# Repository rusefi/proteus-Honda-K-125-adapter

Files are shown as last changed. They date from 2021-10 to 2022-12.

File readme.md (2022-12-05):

[Connector Pinout Spreadhseet, with links to wiring drawings](https://docs.google.com/spreadsheets/d/1G6FDarE99hbd0HSs6bh5kEkZy6p-kYTxa0NcJpE1HUc)

Part of https://github.com/rusefi/rusefi/wiki/Proteus#adapters family

https://github.com/rusefi/rusefi/wiki/Proteus-Honda125

https://www.ebay.com/itm/334206656537

First test mule https://rusefi.com/forum/viewtopic.php?f=2&t=1955

https://github.com/rusefi/rusefi/wiki/Vault-Of-Honda-OEM#dbc-k

https://github.com/rusefi/rusefi/wiki/Honda-Element

x

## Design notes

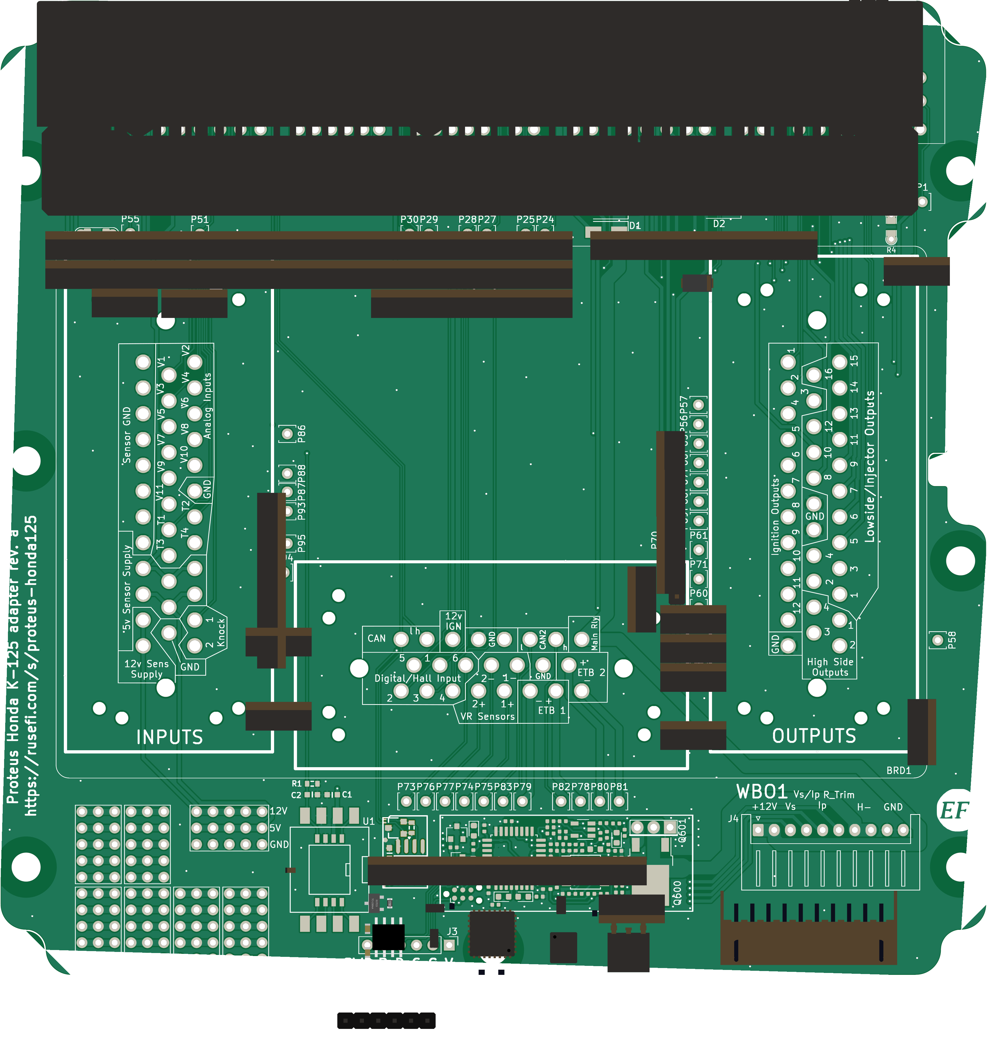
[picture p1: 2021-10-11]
proteus125honda/boards/proteus125honda-a/board/proteus125honda-a.png

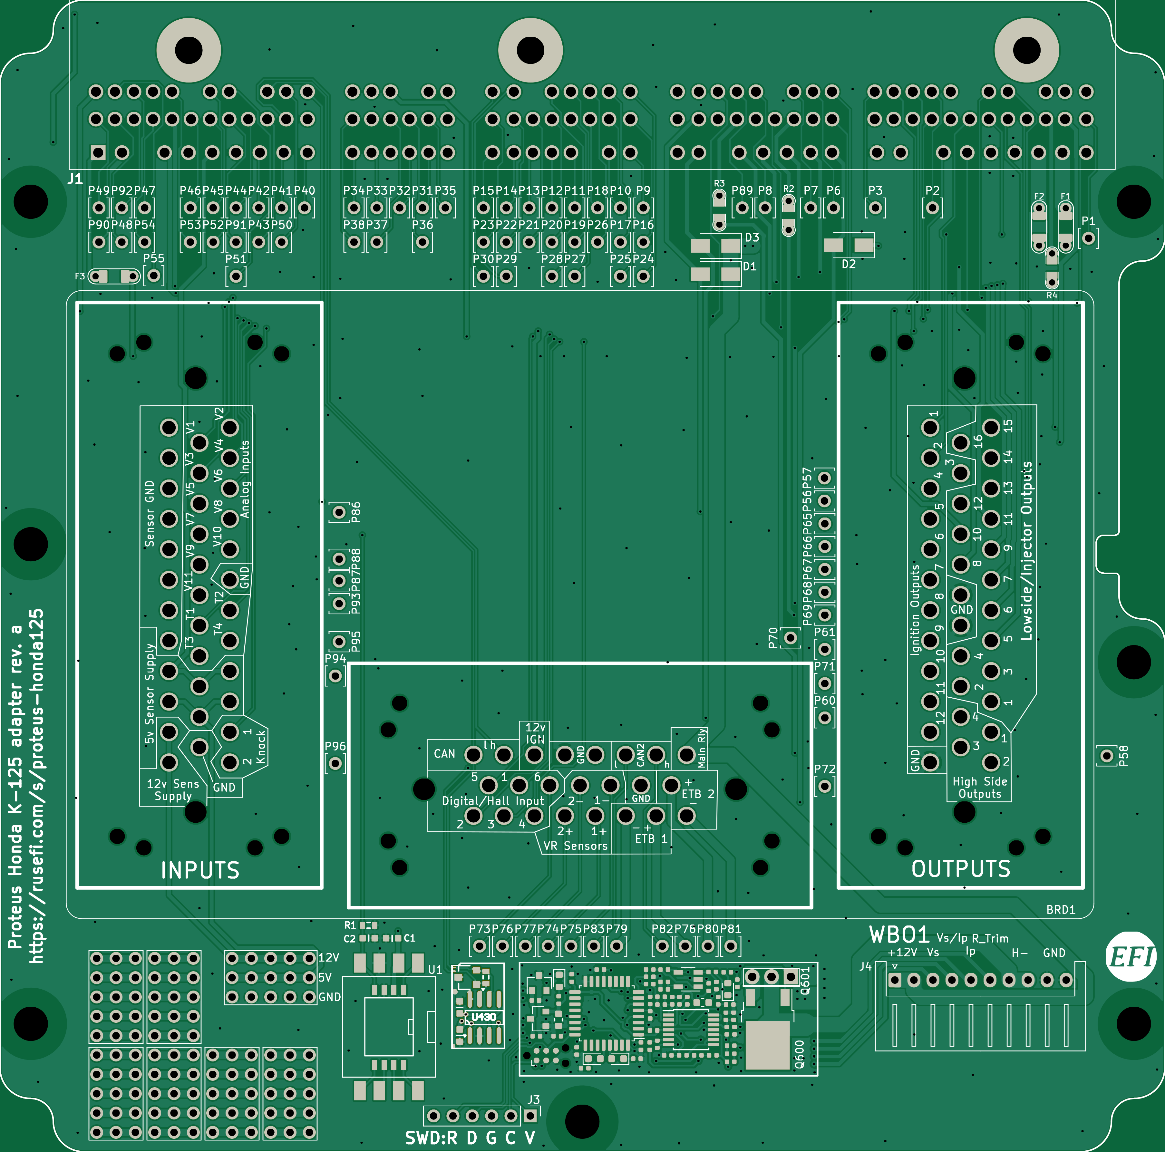
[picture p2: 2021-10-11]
proteus125honda/boards/proteus125honda-a/board/misc/proteus125honda-a-top.png

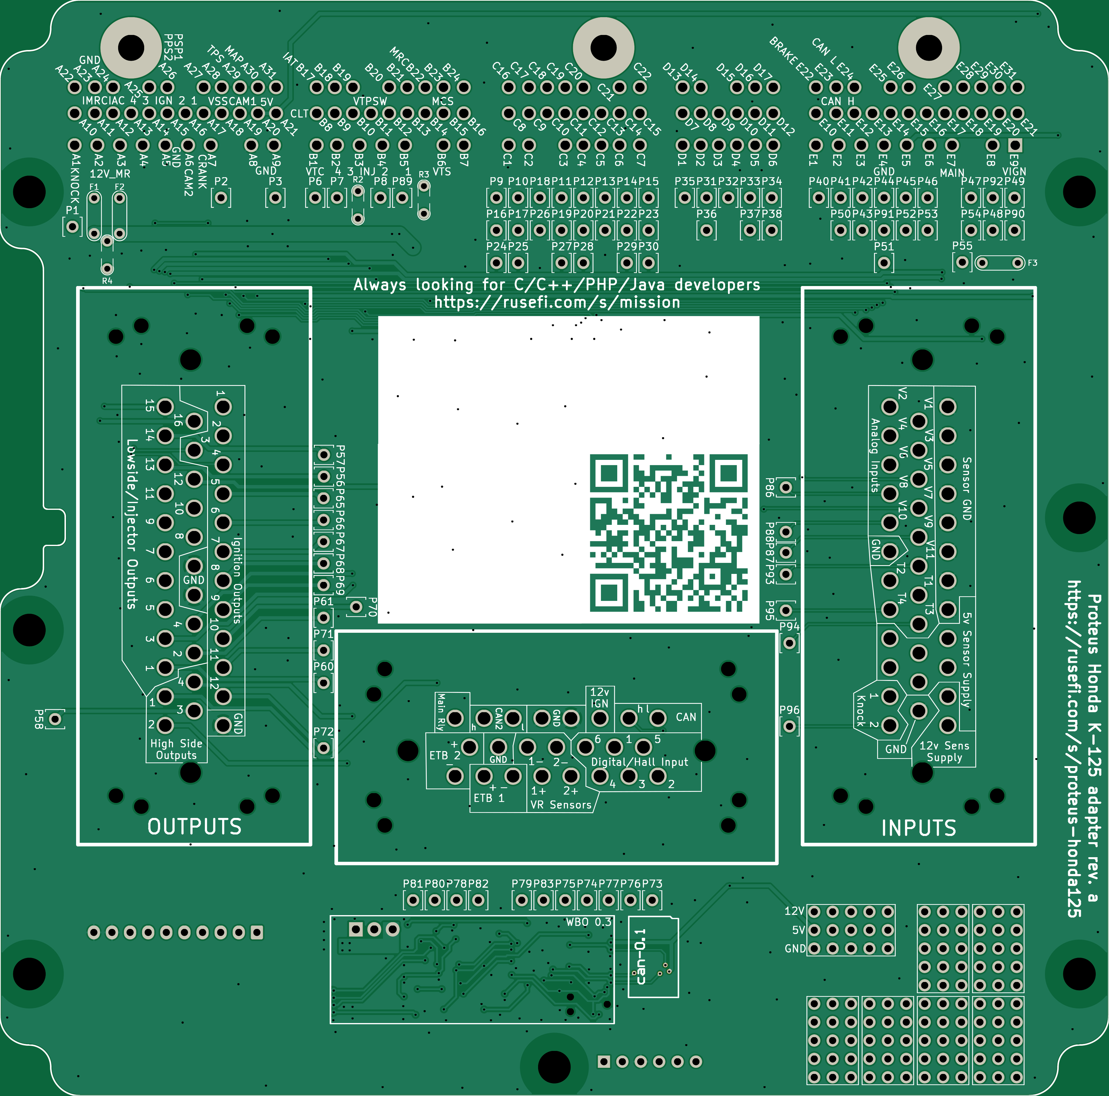
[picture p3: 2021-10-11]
proteus125honda/boards/proteus125honda-a/board/misc/proteus125honda-a-bottom.png

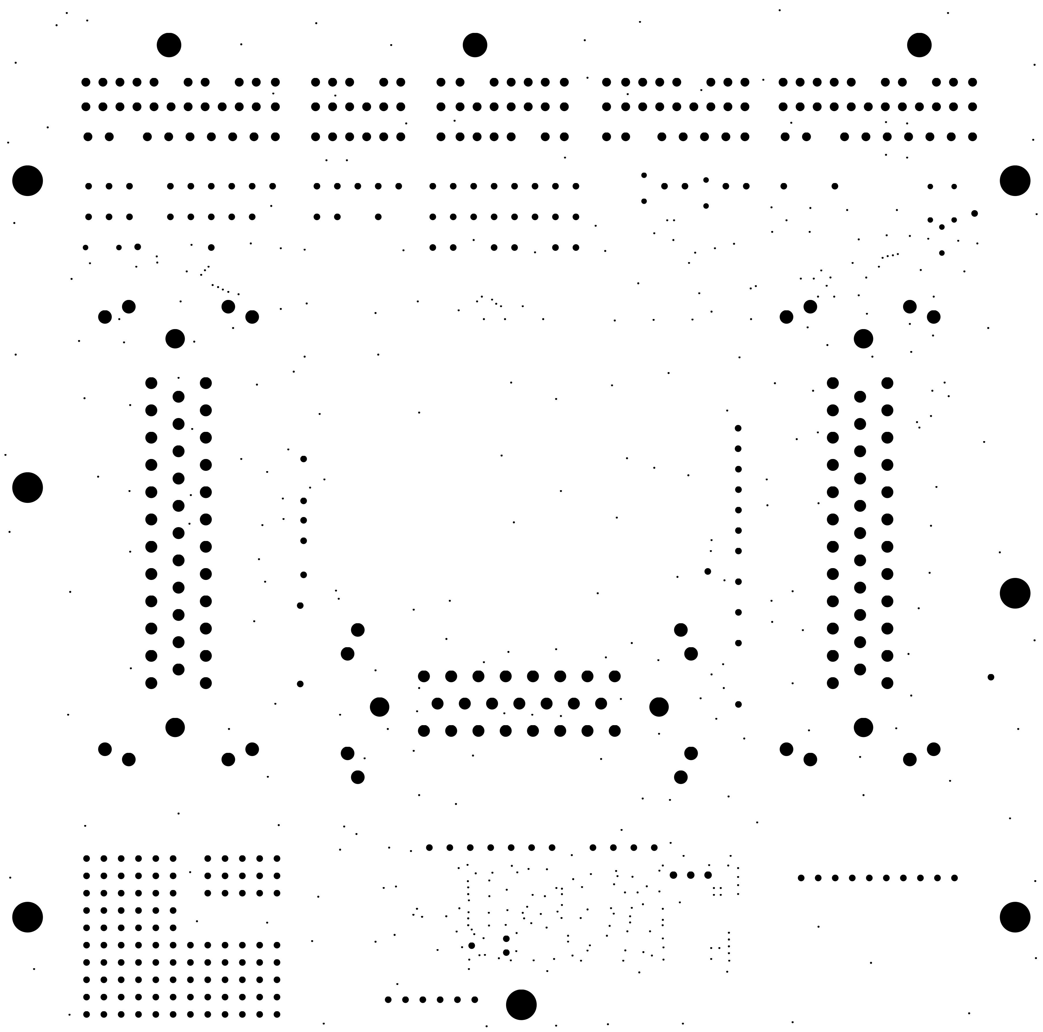
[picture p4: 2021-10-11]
proteus125honda/boards/proteus125honda-a/board/misc/proteus125honda-a-outline.png

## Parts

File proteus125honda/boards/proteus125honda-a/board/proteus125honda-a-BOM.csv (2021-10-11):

Comment | Designator | Footprint | LCSC Part #
proteus | BRD1 | proteus
100n | C1, C430, C431 | C0603 | C14663
47p | C2 | C0603 | C1671
D_Schottky | D1, D2 | D_SMA | C8678
DNP | D3 | D_SMA
Fuse-Pad-Pad | F1, F2, F3 | PAD-1206-PAD | C182446
PROTO_AREA | G1 | PROTO_AREA
PROTO_AREA | G2 | PROTO_AREA
PROTO_AREA | G3 | PROTO_AREA
PROTO_AREA | G4 | PROTO_AREA
PROTO_AREA | G5 | PROTO_AREA
RUSEFI_LOGO | G6 | rusefi_logo
PROTO_AREA | G7 | PROTO_AREA
PROTO_AREA | G8 | PROTO_AREA
1318612-1 | J1 | TE_1318612-1
Conn_01x06 | J3 | PinHeader_1x06_P2.54mm_Vertical
XH-10AW | J4 | JST_XH_S10B-XH-A_1x10_P2.50mm_Horizontal | C14652
Conn_01x01 | J7 | MountingHole_4.5mm
Conn_01x01 | J8 | MountingHole_4.5mm
Conn_01x01 | J9 | MountingHole_4.5mm
Conn_01x01 | J10 | MountingHole_4.5mm
Conn_01x01 | J11 | MountingHole_4.5mm
Conn_01x01 | J12 | MountingHole_4.5mm
Conn_01x01 | J13 | MountingHole_4.5mm
Pad | P1 | PAD-TH
Pad | P2 | PAD-TH
Pad | P3 | PAD-TH
Pad | P6 | PAD-TH
Pad | P7 | PAD-TH
Pad | P8 | PAD-TH
Pad | P9 | PAD-TH
Pad | P10 | PAD-TH
Pad | P11 | PAD-TH
Pad | P12 | PAD-TH
Pad | P13 | PAD-TH
Pad | P14 | PAD-TH
Pad | P15 | PAD-TH
Pad | P16 | PAD-TH
Pad | P17 | PAD-TH
Pad | P18 | PAD-TH
Pad | P19 | PAD-TH
Pad | P20 | PAD-TH
Pad | P21 | PAD-TH
Pad | P22 | PAD-TH
Pad | P23 | PAD-TH
Pad | P24 | PAD-TH
Pad | P25 | PAD-TH
Pad | P26 | PAD-TH
Pad | P27 | PAD-TH
Pad | P28 | PAD-TH
Pad | P29 | PAD-TH
Pad | P30 | PAD-TH
Pad | P31 | PAD-TH
Pad | P32 | PAD-TH
Pad | P33 | PAD-TH
Pad | P34 | PAD-TH
Pad | P35 | PAD-TH
Pad | P36 | PAD-TH
Pad | P37 | PAD-TH
Pad | P38 | PAD-TH
Pad | P40 | PAD-TH
Pad | P41 | PAD-TH
Pad | P42 | PAD-TH
Pad | P43 | PAD-TH
Pad | P44 | PAD-TH
Pad | P45 | PAD-TH
Pad | P46 | PAD-TH
Pad | P47 | PAD-TH
Pad | P48 | PAD-TH
Pad | P49 | PAD-TH
Pad | P50 | PAD-TH
Pad | P51 | PAD-TH
Pad | P52 | PAD-TH
Pad | P53 | PAD-TH
Pad | P54 | PAD-TH
Pad | P55 | PAD-TH
Pad | P56 | PAD-TH
Pad | P57 | PAD-TH
Pad | P58 | PAD-TH
Pad | P60 | PAD-TH
Pad | P61 | PAD-TH
Pad | P65 | PAD-TH
Pad | P66 | PAD-TH
Pad | P67 | PAD-TH
Pad | P68 | PAD-TH
Pad | P69 | PAD-TH
Pad | P70 | PAD-TH
Pad | P71 | PAD-TH
Pad | P72 | PAD-TH
Pad | P73 | PAD-TH
Pad | P74 | PAD-TH
Pad | P75 | PAD-TH
Pad | P76 | PAD-TH
Pad | P77 | PAD-TH
Pad | P78 | PAD-TH
Pad | P79 | PAD-TH
Pad | P80 | PAD-TH
Pad | P81 | PAD-TH
Pad | P82 | PAD-TH
Pad | P83 | PAD-TH
Pad | P86 | PAD-TH
Pad | P87 | PAD-TH
Pad | P88 | PAD-TH
Pad | P89 | PAD-TH
Pad | P90 | PAD-TH
Pad | P91 | PAD-TH
Pad | P92 | PAD-TH
Pad | P93 | PAD-TH
Pad | P94 | PAD-TH
Pad | P95 | PAD-TH
Pad | P96 | PAD-TH
51k | R1 | R0603 | C23196
Jumper-Pad-Pad | R2, R3, R4 | PAD-0805-PAD | C17477
MPXxx6115A | U1 | MPX_SOP_SSOP
1u | C600, C607, C609, C610, C611 | C0402 | C52923
100n | C601, C602, C605, C608, C612, C613, C614, C615 | C0402 | C1525
33n | C603 | C0402 | C1585
DNP | C604 | C0402
DNP | C606 | C0402
4.7u | C616 | C0603 | C19666
LED-RED-0603 | D600, D603 | LED-0603 | C2286
LED-GREEN-0603 | D601 | LED-0603 | C72043
LED-BLUE-0603 | D602 | LED-0603 | C72041
VNP28N04-E | Q601 | TO-220-3_Vertical | C263002
1k | R600, R601, R616, R617, R622, R626, R627, R628 | R0402 | C11702
68k | R602, R603 | R0402 | C36871
10k | R604, R605, R613, R614, R618, R619, R625 | R0402 | C25744
10 | R606 | R0402 | C25077
22k | R607 | R0402 | C25768
47 | R608 | R0402 | C25118
61.9 | R609 | R0603 | C23092
20k | R610, R611, R612 | R0402 | C25765
100k | R615, R621 | R0402 | C25741
27k | R620, R623 | R0402 | C25771
3.3k | R624 | R0402 | C25890
MCP6004 | U600 | TSSOP14 | C50282
AD8628 | U601 | TSOT23-5 | C29309
REF3033 | U603 | SOT-23 | C36658
XC6206P332MR | U604 | SOT-23 | C5446
PESD1CAN | D430 | SOT-23 | C343993
120 | R430 | R0603 | C22787
TJA1051T/3/1J | U430 | SO8 | C38695

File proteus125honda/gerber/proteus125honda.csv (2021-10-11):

Comment | Designator | Footprint | LCSC Part #
proteus | BRD1 | kicad6-libraries:proteus
100n | C1 | hellen-one-common:C0603 | C14663
47p | C2 | hellen-one-common:C0603 | C1671
D_Schottky | D1 | Diode_SMD:D_SMA | C8678
D_Schottky | D2 | Diode_SMD:D_SMA | C8678
DNP | D3 | Diode_SMD:D_SMA
Fuse-Pad-Pad | F1 | hellen-one-common:PAD-1206-PAD | C182446
Fuse-Pad-Pad | F2 | hellen-one-common:PAD-1206-PAD | C182446
Fuse-Pad-Pad | F3 | hellen-one-common:PAD-1206-PAD | C182446
PROTO_AREA | G1 | hellen-one-common:PROTO_AREA
PROTO_AREA | G2 | hellen-one-common:PROTO_AREA
PROTO_AREA | G3 | hellen-one-common:PROTO_AREA
PROTO_AREA | G4 | hellen-one-common:PROTO_AREA
PROTO_AREA | G5 | hellen-one-common:PROTO_AREA
RUSEFI_LOGO | G6 | kicad6-libraries:rusefi_logo
PROTO_AREA | G7 | hellen-one-common:PROTO_AREA
PROTO_AREA | G8 | hellen-one-common:PROTO_AREA
1318612-1 | J1 | kicad6-libraries:TE_1318612-1
Conn_01x06 | J3 | Connector_PinHeader_2.54mm:PinHeader_1x06_P2.54mm_Vertical
XH-10AW | J4 | Connector_JST:JST_XH_S10B-XH-A_1x10_P2.50mm_Horizontal | C14652
Conn_01x01 | J7 | MountingHole:MountingHole_4.5mm
Conn_01x01 | J8 | MountingHole:MountingHole_4.5mm
Conn_01x01 | J9 | MountingHole:MountingHole_4.5mm
Conn_01x01 | J10 | MountingHole:MountingHole_4.5mm
Conn_01x01 | J11 | MountingHole:MountingHole_4.5mm
Conn_01x01 | J12 | MountingHole:MountingHole_4.5mm
Conn_01x01 | J13 | MountingHole:MountingHole_4.5mm
Module-wbo-0.3 | M1 | hellen-one-wbo-0.3:wbo
Module-can-0.1 | M2 | hellen-one-can-0.1:can
Pad | P1 | hellen-one-common:PAD-TH
Pad | P2 | hellen-one-common:PAD-TH
Pad | P3 | hellen-one-common:PAD-TH
Pad | P6 | hellen-one-common:PAD-TH
Pad | P7 | hellen-one-common:PAD-TH
Pad | P8 | hellen-one-common:PAD-TH
Pad | P9 | hellen-one-common:PAD-TH
Pad | P10 | hellen-one-common:PAD-TH
Pad | P11 | hellen-one-common:PAD-TH
Pad | P12 | hellen-one-common:PAD-TH
Pad | P13 | hellen-one-common:PAD-TH
Pad | P14 | hellen-one-common:PAD-TH
Pad | P15 | hellen-one-common:PAD-TH
Pad | P16 | hellen-one-common:PAD-TH
Pad | P17 | hellen-one-common:PAD-TH
Pad | P18 | hellen-one-common:PAD-TH
Pad | P19 | hellen-one-common:PAD-TH
Pad | P20 | hellen-one-common:PAD-TH
Pad | P21 | hellen-one-common:PAD-TH
Pad | P22 | hellen-one-common:PAD-TH
Pad | P23 | hellen-one-common:PAD-TH
Pad | P24 | hellen-one-common:PAD-TH
Pad | P25 | hellen-one-common:PAD-TH
Pad | P26 | hellen-one-common:PAD-TH
Pad | P27 | hellen-one-common:PAD-TH
Pad | P28 | hellen-one-common:PAD-TH
Pad | P29 | hellen-one-common:PAD-TH
Pad | P30 | hellen-one-common:PAD-TH
Pad | P31 | hellen-one-common:PAD-TH
Pad | P32 | hellen-one-common:PAD-TH
Pad | P33 | hellen-one-common:PAD-TH
Pad | P34 | hellen-one-common:PAD-TH
Pad | P35 | hellen-one-common:PAD-TH
Pad | P36 | hellen-one-common:PAD-TH
Pad | P37 | hellen-one-common:PAD-TH
Pad | P38 | hellen-one-common:PAD-TH
Pad | P40 | hellen-one-common:PAD-TH
Pad | P41 | hellen-one-common:PAD-TH
Pad | P42 | hellen-one-common:PAD-TH
Pad | P43 | hellen-one-common:PAD-TH
Pad | P44 | hellen-one-common:PAD-TH
Pad | P45 | hellen-one-common:PAD-TH
Pad | P46 | hellen-one-common:PAD-TH
Pad | P47 | hellen-one-common:PAD-TH
Pad | P48 | hellen-one-common:PAD-TH
Pad | P49 | hellen-one-common:PAD-TH
Pad | P50 | hellen-one-common:PAD-TH
Pad | P51 | hellen-one-common:PAD-TH
Pad | P52 | hellen-one-common:PAD-TH
Pad | P53 | hellen-one-common:PAD-TH
Pad | P54 | hellen-one-common:PAD-TH
Pad | P55 | hellen-one-common:PAD-TH
Pad | P56 | hellen-one-common:PAD-TH
Pad | P57 | hellen-one-common:PAD-TH
Pad | P58 | hellen-one-common:PAD-TH
Pad | P60 | hellen-one-common:PAD-TH
Pad | P61 | hellen-one-common:PAD-TH
Pad | P65 | hellen-one-common:PAD-TH
Pad | P66 | hellen-one-common:PAD-TH
Pad | P67 | hellen-one-common:PAD-TH
Pad | P68 | hellen-one-common:PAD-TH
Pad | P69 | hellen-one-common:PAD-TH
Pad | P70 | hellen-one-common:PAD-TH
Pad | P71 | hellen-one-common:PAD-TH
Pad | P72 | hellen-one-common:PAD-TH
Pad | P73 | hellen-one-common:PAD-TH
Pad | P74 | hellen-one-common:PAD-TH
Pad | P75 | hellen-one-common:PAD-TH
Pad | P76 | hellen-one-common:PAD-TH
Pad | P77 | hellen-one-common:PAD-TH
Pad | P78 | hellen-one-common:PAD-TH
Pad | P79 | hellen-one-common:PAD-TH
Pad | P80 | hellen-one-common:PAD-TH
Pad | P81 | hellen-one-common:PAD-TH
Pad | P82 | hellen-one-common:PAD-TH
Pad | P83 | hellen-one-common:PAD-TH
Pad | P86 | hellen-one-common:PAD-TH
Pad | P87 | hellen-one-common:PAD-TH
Pad | P88 | hellen-one-common:PAD-TH
Pad | P89 | hellen-one-common:PAD-TH
Pad | P90 | hellen-one-common:PAD-TH
Pad | P91 | hellen-one-common:PAD-TH
Pad | P92 | hellen-one-common:PAD-TH
Pad | P93 | hellen-one-common:PAD-TH
Pad | P94 | hellen-one-common:PAD-TH
Pad | P95 | hellen-one-common:PAD-TH
Pad | P96 | hellen-one-common:PAD-TH
51k | R1 | hellen-one-common:R0603 | C23196
Jumper-Pad-Pad | R2 | hellen-one-common:PAD-0805-PAD | C17477
Jumper-Pad-Pad | R3 | hellen-one-common:PAD-0805-PAD | C17477
Jumper-Pad-Pad | R4 | hellen-one-common:PAD-0805-PAD | C17477
MPXxx6115A | U1 | kicad6-libraries:MPX_SOP_SSOP

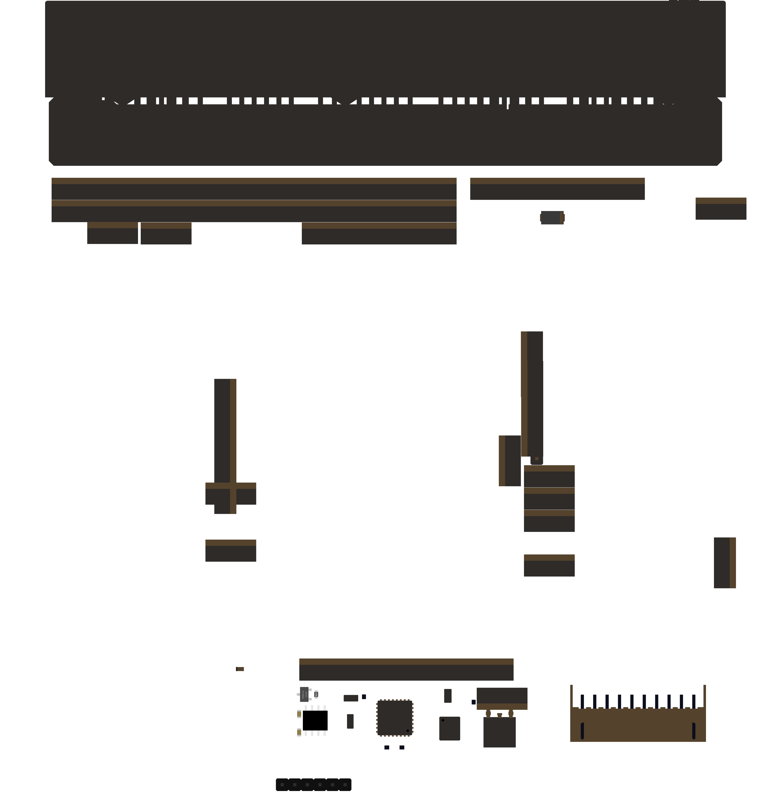
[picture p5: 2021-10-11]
proteus125honda/boards/proteus125honda-a/board/misc/proteus125honda-a-components.png

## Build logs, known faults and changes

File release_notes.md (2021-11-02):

rev 0.1: initial version
known issues:
  * IAC shorted to MR - need R4 removed, need trace cut
  * E12 FAN contron not wired
  * D2 VTC diode wrong orientation

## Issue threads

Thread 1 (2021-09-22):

Connector type and placement

Qwerty-OFF, 2021-09-22:
To determine the outline of the board, we need to select vertical or horizontal connectors and decide how to place them on the board

horizontal
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

vertical
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

rusefillc, 2021-09-22:
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

rusefillc, 2021-09-22:
horizontal option it totally unrealistic
vertical option maaaaaaaybe

it really starts to look like we will have to solder wires. let's go with vertical even while in reality we are probably soldering wires

Also let's just go with "normal" connector matching proteus, pin 1 of proteus going to pin 1 on the board. The wires would have to twist and we will just live with that for now.

Closed 2021-10-02.

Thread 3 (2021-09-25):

pin clarifications

rusefillc, 2021-09-25:
E17: looks like that's fuel pump relay we definitely want it!

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
A10: narrowband exhaust oxygen sensor heater, not MAF heater, just a via
A28: narrowband exhaust oxygen sensor something, for our applications we need wideband module, so just via
A31: same

B21: OUT_PURGE just via
E8: not Mass Air Flow relay but exhaust Air/Fuel mixture heater relay, we might actually use it for WBO heater control? not sure. just a via.

E19: something not important just VIA

E14: fuel tank pressure sensor, just a via

Closed 2021-09-30.

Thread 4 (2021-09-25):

Pinout table needs better pin names

rusefillc, 2021-09-25:
https://docs.google.com/spreadsheets/d/1G6FDarE99hbd0HSs6bh5kEkZy6p-kYTxa0NcJpE1HUc has horrible abbreviations not human-readable pin info

https://docs.google.com/spreadsheets/d/1G6FDarE99hbd0HSs6bh5kEkZy6p-kYTxa0NcJpE1HUc has links to wiring drawings

At the moment we mostly care about 2003 Honda Element since that's the first test mule

BeerMoneyMotorsports, 2021-12-14:
@rusefillc sorry i have missed this, do you still need my support?

Closed 2021-12-14.

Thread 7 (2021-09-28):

Baro sensor

rusefillc, 2021-09-28:
Can we check JLC for pressure sensors one more time? If nothing we need an easy to hand solder footprint

Qwerty-OFF, 2021-09-29:
JLC has resistive sensors like this
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
MPS-3117-006GC-A3_C242002
Can we use it with proteus?
There are also a small number of sensors with i2c bus, but I see no way to connect them to proteus.

rusefillc, 2021-09-29:
Analog Temp 3 and Analog Temp 4 are usually unused (AT1 and AT2 are CLT and IAT), I believe 2.7K or something under 5K pull-up on those

rusefillc, 2021-09-29:
@mck1117 says "those sensors are all gauge pressure
aka useless for baro
must be absolute"

non-jlc option would be https://github.com/rusefi/rusefi/tree/master/hardware/Map_MPX footprint

Qwerty-OFF, 2021-09-30:
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
Done

Closed 2021-09-30.

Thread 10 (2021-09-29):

At least some silkscreen of vehicle connector on the back

rusefillc, 2021-09-29:
At least for pins where we have lots of space please add silk of vehicle connector on the back

Qwerty-OFF, 2021-09-30:
Done

Closed 2021-09-30.

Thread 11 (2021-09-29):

23 pin proteus pin

rusefillc, 2021-09-29:
pins 21 and 22 are NOT CAN see https://rusefi.com/docs/pinouts/proteus/

there is also confusion between older 23 pinout (some residual mentioning at https://github.com/rusefi/rusefi/wiki/HOWTO-M73-v12-on-Proteus#black-23-pin-776228-1-on-black-proteus-02 and more current new 23 pinout like https://github.com/rusefi/rusefi/wiki/HOWTO-M73-v12-on-Proteus#black-23-pin-776228-1-on-green-proteus-03)

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

rusefillc, 2021-09-29:
Let's double-check whole connector?

I assume this was copy-pasted into all boards, let's NOT fix now in other boards to reduce chance of conflicts with data entry

Qwerty-OFF, 2021-09-30:
Fixed, please check

rusefillc, 2021-10-01:
@mck1117 says it's https://rusefi.com/docs/pinouts/proteus/ which is wrong

rusefillc, 2021-10-01:
https://github.com/rusefi/rusefi/issues/3291

rusefillc, 2021-10-01:
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

Qwerty-OFF, 2021-10-01:
Fixed
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

Closed 2021-10-01.

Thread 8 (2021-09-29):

Proteus connectors layout

rusefillc, 2021-09-29:
@mck1117 says "those connectors are backwards. please keep orientation same as real proteus"

which raises the question: on this board do we have space to lay connectors _exactly_ like on Proteus to allow soldering proteus without connectors like a shield?

like https://rusefi.com/forum/viewtopic.php?p=42098#p42098
like https://rusefi.com/forum/viewtopic.php?f=4&t=1701 which is https://github.com/CrazyStriker/hw_PnProteus_72P_NB2

rusefillc, 2021-09-29:
Speaking of Proteus connector layout can we please also copy-paste the nice proteus connector silk?

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

Qwerty-OFF, 2021-09-30:
I made the Proteus component. Do we use it in this board, or do we leave everything as it is?
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

rusefillc, 2021-09-30:
one of the options i am considering is a 35 pin harness patch cord, one side other side black. that case we use two of same patch cords

this would invert "black" and "white" on the adapter

can we go with "power" and "analog" terms instead of "black" and "white" on the adapter?

rusefillc, 2021-09-30:
@mck1117 FYI ^^^

Qwerty-OFF, 2021-09-30:
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
Used proteus-compatible footprint

Closed 2021-09-30.

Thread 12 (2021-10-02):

Account for unpopulated Proteus fly-back diodes

rusefillc, 2021-10-02:
two of Proteus four fly-back diodes are never populated since JLC and single side assembly

the best way for us is to have our own fly backs if we use those two channels and a text note on the schematics that Proteus potentially has second diode while usually it does not

See https://github.com/mck1117/proteus/issues/104

Qwerty-OFF, 2021-10-02:
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

rusefillc, 2021-10-02:
love it :)

Closed 2021-10-02.

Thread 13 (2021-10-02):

VTEC and VTC seem to be high-side solenoids

rusefillc, 2021-10-02:
open question what current do we need and what current does Proteus support here

Do we need any fly-back here?

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

rusefillc, 2021-10-02:
@mck1117 @blundar ^^^

mck1117, 2021-10-02:
VTEC is just on/off (no PWM), so no flyback diode needed.  The high side outputs on Proteus should be able to handle vtec no problem.

Qwerty-OFF, 2021-10-02:
Done
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

blundar, 2021-10-03:
I'd be a little more cautious with VTC than Vtec.  You'll need to run a
variable PWM signal to VTC so flyback might be a little bit more of an
issue.
-D

On Sat, Oct 2, 2021 at 4:38 PM Vladimir Vinogradov ***@***.***>
wrote:

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

rusefillc, 2021-10-03:
let's add flyback for VTC and DNP flyback footprint for Vtec just to be safe

blundar, 2021-10-03:
Vtec solenoid has a flyback diode on OEM ECU.  Typically 0.8-1.2A draw.
Not a very angry solenoid.
-D

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

rusefillc, 2021-10-03:
let's add flyback for both VTC and VTEC based on what @blundar says

mck1117, 2021-10-03:
No - you actually don't want flyback on VTEC.  VTEC is on-off, which means you want it to turn off quickly, which means no flyback.

blundar, 2021-10-03:
I'm just relaying what OEM driver circuitry looks like...  They have a
1N4001 flyback diode on OBD1 and what looks like a SOD123 package on a
accord K ECU.  It's not SMA big, it's not SOD323 small.

On Sun, Oct 3, 2021 at 2:05 AM Matthew Kennedy ***@***.***>
wrote:

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

blundar, 2021-10-03:
The OEM ECU code also has timer code to delay transitions from non-vtec to
vtec fuel/ign, assuming certain delays in activation + deactivation.  It's
been 10+ years since I was wafting in that assembly but I distinctly
remember asymmetric delays.

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

Qwerty-OFF, 2021-10-03:
Added DNP flyback footprint
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

rusefillc, 2021-10-03:
VTC should definitely be populated

Qwerty-OFF, 2021-10-03:
Fixed

Closed 2021-10-11.

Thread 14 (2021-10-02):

What kind of IAC is that?

rusefillc, 2021-10-02:
this IAC is what? idle air control? why does it have three wires GND +12v and ECU? what is the ECU wire?

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

rusefillc, 2021-10-02:
https://www.k20a.org/threads/iacv-pinouts.98463/ says low side, inductive load.. why 3rd wire?!

blundar, 2021-10-03:
https://www.aemelectronics.com/files/instructions/30-6030%20Series%202%20Plug%20&%20Play%20EMS.pdf

AEM list it as using PW1, which is typically low side.

https://www.aemelectronics.com/sites/default/files/aem_product_instructions/30-3502_01-05_Honda_K_Series_PnP_Harness_Instructions.pdf

AEM lists it as " Lowside switch, 4A max with internal f ly back diode.
Inductiv e load should NOT have full time power"

Really not sure why the ground is there .
-Dave

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

rusefillc, 2021-10-03:
Let's wire as "normal" low side solenoid with a jumper just in case

Qwerty-OFF, 2021-10-03:
With a flyback diode?

rusefillc, 2021-10-03:
yes, idle valve solenoids always a flyback.

Qwerty-OFF, 2021-10-03:
Done
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

Closed 2021-10-03.

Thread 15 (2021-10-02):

D15 ETB Relay

rusefillc, 2021-10-02:
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

@Qwerty-OFF which vehicle has that? can you please fill in D15 in https://docs.google.com/spreadsheets/d/1G6FDarE99hbd0HSs6bh5kEkZy6p-kYTxa0NcJpE1HUc/ ?

Qwerty-OFF, 2021-10-02:
Element 2003, Element 2008, acura TSX 2005
Filled

rusefillc, 2021-10-02:
Let's wire in default configuration looks like a useful wire

looks like low-side?

Qwerty-OFF, 2021-10-02:
Done
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

Closed 2021-10-02.

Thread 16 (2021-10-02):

Charging system

rusefillc, 2021-10-02:
What wires are those do we care?

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

rusefillc, 2021-10-02:
https://www.k20a.org/threads/which-is-the-field-wire-on-a-k-series-alternator.73114/

https://www.hondata.com/forum/viewtopic.php?t=5383

B10 is definitely charging light on the dash let's do low side control with a via/jumper just in case

rusefillc, 2021-10-02:
B13 alternator control? let's wire to high side with a jumper just in case?

rusefillc, 2021-10-02:
and B18 let's leave as is that looks to be feedback from alternator

Qwerty-OFF, 2021-10-02:
Done
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

Closed 2021-10-03.

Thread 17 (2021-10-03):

WBO: please make connector more self-contained

rusefillc, 2021-10-03:
current 8 pin WBO headers is requiring extra wiring outside of the 8 pin right?

let's have a more full 10 pin connector

if 90 degree angled version is available let's place 90 degree angled version not far from the edge facing the edge. maybe 3cm away from board edge?

Qwerty-OFF, 2021-10-03:
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

Closed 2021-10-03.

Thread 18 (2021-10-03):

connectors silk

rusefillc, 2021-10-03:
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

let's replace with white/black/black with "inputs / (nothing in the middle) / outputs"

Qwerty-OFF, 2021-10-03:
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

Closed 2021-10-03.

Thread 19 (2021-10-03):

Polycase?

rusefillc, 2021-10-03:
What is the closest polycase case?

rusefillc, 2021-10-03:
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

rusefillc, 2021-10-04:
https://www.polycase.com/jb-65 ?

stefanst, 2021-10-04:
How will this be mounted? Make a custom aluminum (or as Simon and I would say Aluminium) bracket? Case and mounting solution go hand-in-hand.
These guys may be able to make brackets, depending on complexity: https://www.oshcut.com/bending/

Does anybody have mounting dimensions/directions?

rusefillc, 2021-10-04:
@Qwerty-OFF can you please insert 3D of this proteus into 3D of https://www.polycase.com/jb-65 and see how many of bottom mounting points we can align?

stefanst, 2021-10-04:
Clarification: I was asking about how the case gets mounted in the car. Not how the PCB is mounted in the case.
Also: Why are we going off OEM PCB dimensions? Don't we just need the connector dimensions and then mounting of the PROTEUS somewhere behind it?

rusefillc, 2021-10-04:
Oh, gotcha on vehicle mounting

Exploring off OEM PCB so that we can go BOTH oem and polycase.  Also sometimes the space available is more or less OEM shape like this specific Honda has a very specific nook for the ECU.

stefanst, 2021-10-04:
It might be helpful to know the size of the nook then.

Qwerty-OFF, 2021-10-04:
We can try add this holes
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

stefanst, 2021-10-04:
We can already see that this solution would be weird du to the angular sides of the desktop-type housing. The connector-area will look screwy. A more boxy shape would be better I think. Hence the need to know the size of the cubby it's supposed to go into.

rusefillc, 2021-10-04:
@stefanst very limited polycase options between 6x6 to 8x8

As on ONLY this one

stefanst, 2021-10-04:
@rusefillc can we go beyond/outside of 6x6 and 8x8? How about height?
If machining in house by Polycase is not needed, we can possibly find an alternate supplier and forgo Polycase.
Or tell us that this is the case to use and "just make it work".

rusefillc, 2021-10-04:
@Qwerty-OFF thank you for the 3D!

https://www.polycase.com/jb-65 does not work for us, no need to have these holes

stefanst, 2021-10-04:
Other options:
https://www.takachi-enclosure.com/assets/attachments/images/ex-amp_catalog.pdf
186.5 x 43.5 x 177
https://www.takachi-enclosure.com/assets/attachments/images/pff_catalog.pdf
180 x 150 x 30

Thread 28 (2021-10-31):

ECU powered by USB engages main relay

rusefillc, 2021-10-31:
i plug in USB while ignition key is OFF

this turns ECU on and I hear some relay engaging, that's UNEXPECTED

could be HW or SW issue

Qwerty-OFF, 2021-10-31:
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

rusefillc, 2021-10-31:
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

Qwerty-OFF, 2021-11-02:
I see no reason for this on the adapter board. Are you sure that this main relay is activated?

rusefillc, 2021-11-02:
pins says
pin PB5: Main Relay

gpio_pins says
Main Relay 1

readpin PB5 says
pin PB5 value 1

looks like software issue

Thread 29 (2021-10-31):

VTC control needs diode

rusefillc, 2021-10-31:
i have duty cycle change from 5% to 95% of VTC / HS2 and no results on shaft position

rusefillc, 2021-10-31:
this was SW configuration issue, not HW issue

rusefillc, 2021-10-31:
@mck1117 says

high side outputs have no diode, so it will make lots of heat and have poor control
Should work better with less duty cycle
Diode from gnd to switched pin
Non-stripe goes to gnd
Stripe goes to vvt

rusefillc, 2021-11-01:
hello diode to +12MR

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

rusefillc, 2021-11-01:
between better PID settings and flipped diode VVT/VTC control is much happier

TODO fix diode on adapter

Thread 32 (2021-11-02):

Wire radiator FAN relay

rusefillc, 2021-11-02:
E12 to

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

rusefillc, 2021-11-02:
2021-11-02_16_42_42_831: EngineState: Fan Relay 2 1
2021-11-02_16_42_42_833: EngineState: Fan Relay 1

pin PD7: Fan Relay

readpin PD7
EngineState: pin PD7 value 1

rusefillc, 2021-11-04:
FAN works with harness fix

still TODO: add trace on PCB

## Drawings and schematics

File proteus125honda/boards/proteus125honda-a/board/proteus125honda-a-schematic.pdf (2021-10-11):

## P58 P60 P61 P73 P75 P74 P76 P77

J2 XH-10A DNP | 1 10 11 12 13 14 15 | 2 3 4 5 6 7 8 9 PROTO_AREAGND

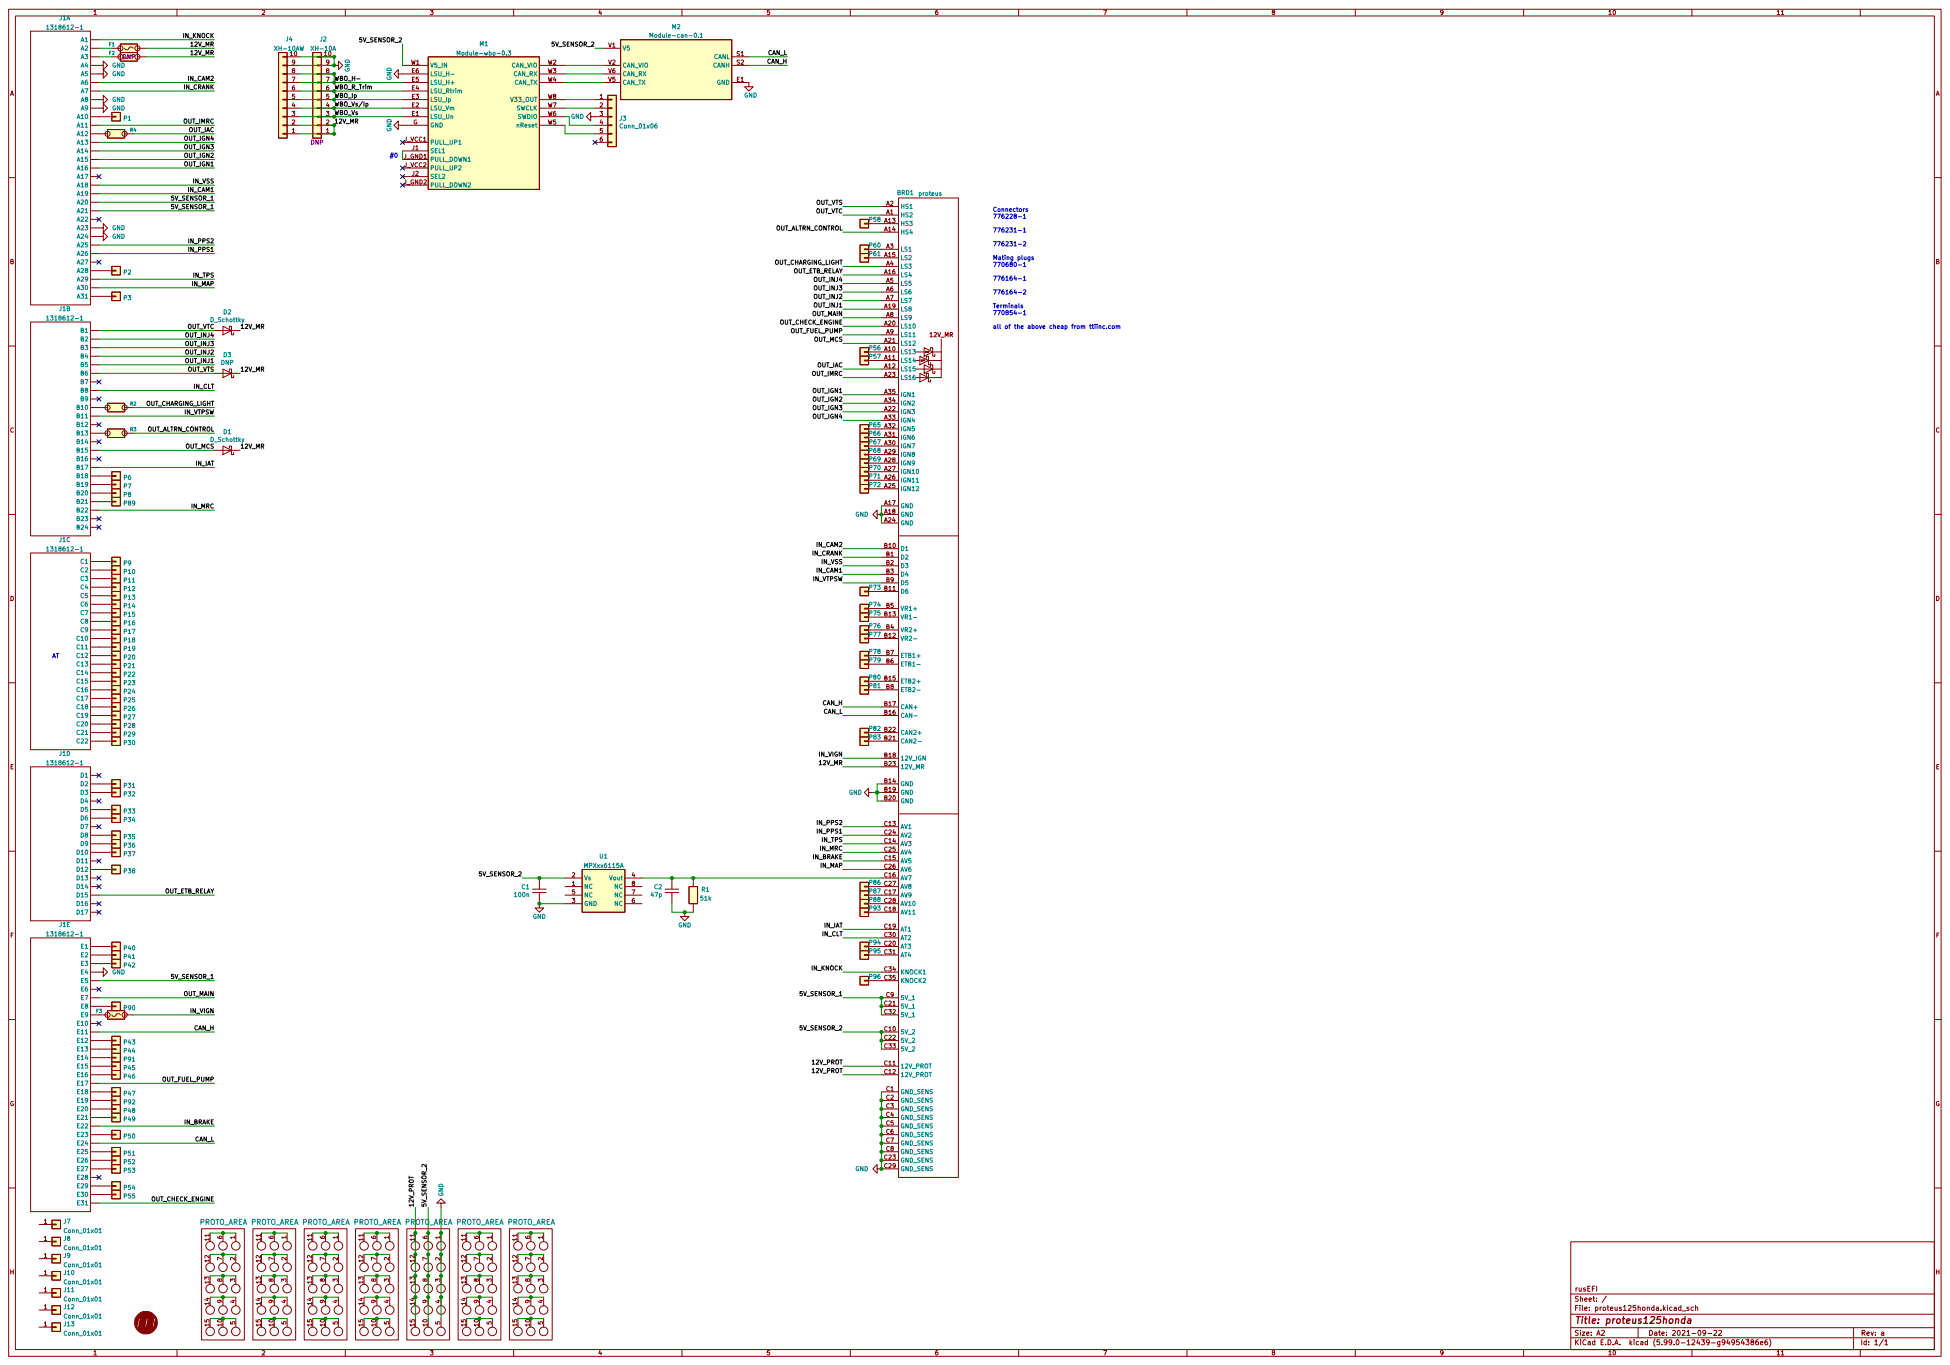
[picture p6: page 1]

all of the above cheap from ttiinc.com

1kR600

3.3k R623

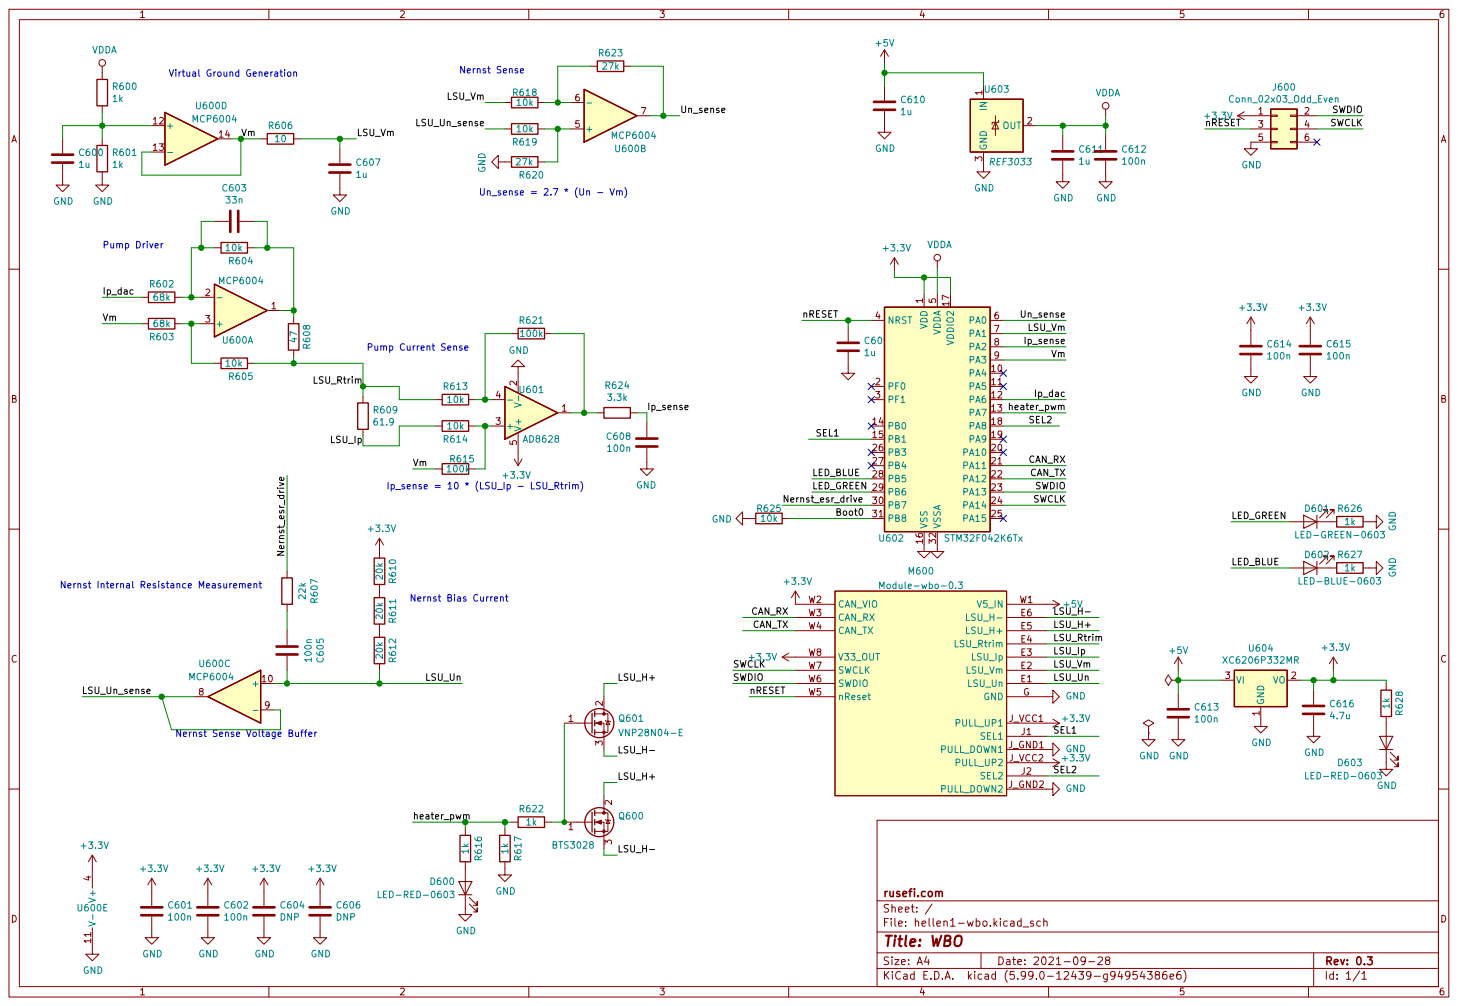
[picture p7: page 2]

Pump Current Sense Nernst Sense

LSU_Vm
Pump Driver Nernst Internal Resistance Measurement

1 VO 2 VI 3 U604 XC6206P332MR GND GND

1 PA4 10 PA5 11 PA6 12 PA7 13 PB0 14 PB1 15 VSS 16 VDDIO2 17 PA8 18 PA9 19 PF0 2 PA10 20 PA11 21 PA12 22 PA13 23 PA14 24 PA15 25 PB3 26 PB4 27 PB5 28 PB6 29 PF1 3 PB7 30 PB8 31 VSSA 32 NRST 4 VDDA

LED-RED-0603 ¹⁰⁰n C⁶⁰⁵ C604 DNP

Nernst Sense Voltage Buffer

1k GND GND R⁶¹⁶ ¹k

File: hellen1-wbo.kicad_sch Sheet: / rusefi.com

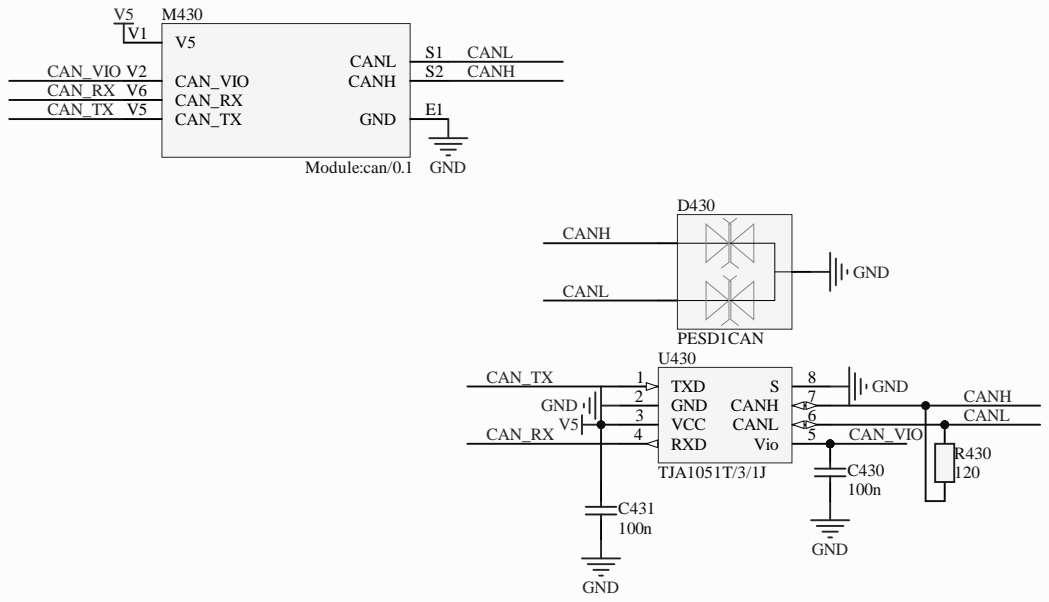
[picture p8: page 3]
andreika; Size:; Author:; Date:; Revision:; Sheet; PESD1CAN; GND; CANH; CANL; TXD 1 GND 2 VCC 3; Vio; 5 RXD 4; 6 CANH; TJA1051T/3/1J; CANH CANL; CAN_TX; CAN_RX; CAN_VIO; CAN_VIO V2; S2 CANL; CAN_TX V5; CAN_RX V6; Module:can/0.1

Hellen-One CAN
Title:

rusEFI EMS
Hellen-One Platform
https://rusefi.com/s/hellen72

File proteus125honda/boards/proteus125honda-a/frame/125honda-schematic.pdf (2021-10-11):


LSU_H- E6 GND G LSU_Rtrim E4

IN_CRANK OUT_IMRC OUT_IAC | | LSU_Ip E3

LSU_Un E1

all of the above cheap from ttiinc.com

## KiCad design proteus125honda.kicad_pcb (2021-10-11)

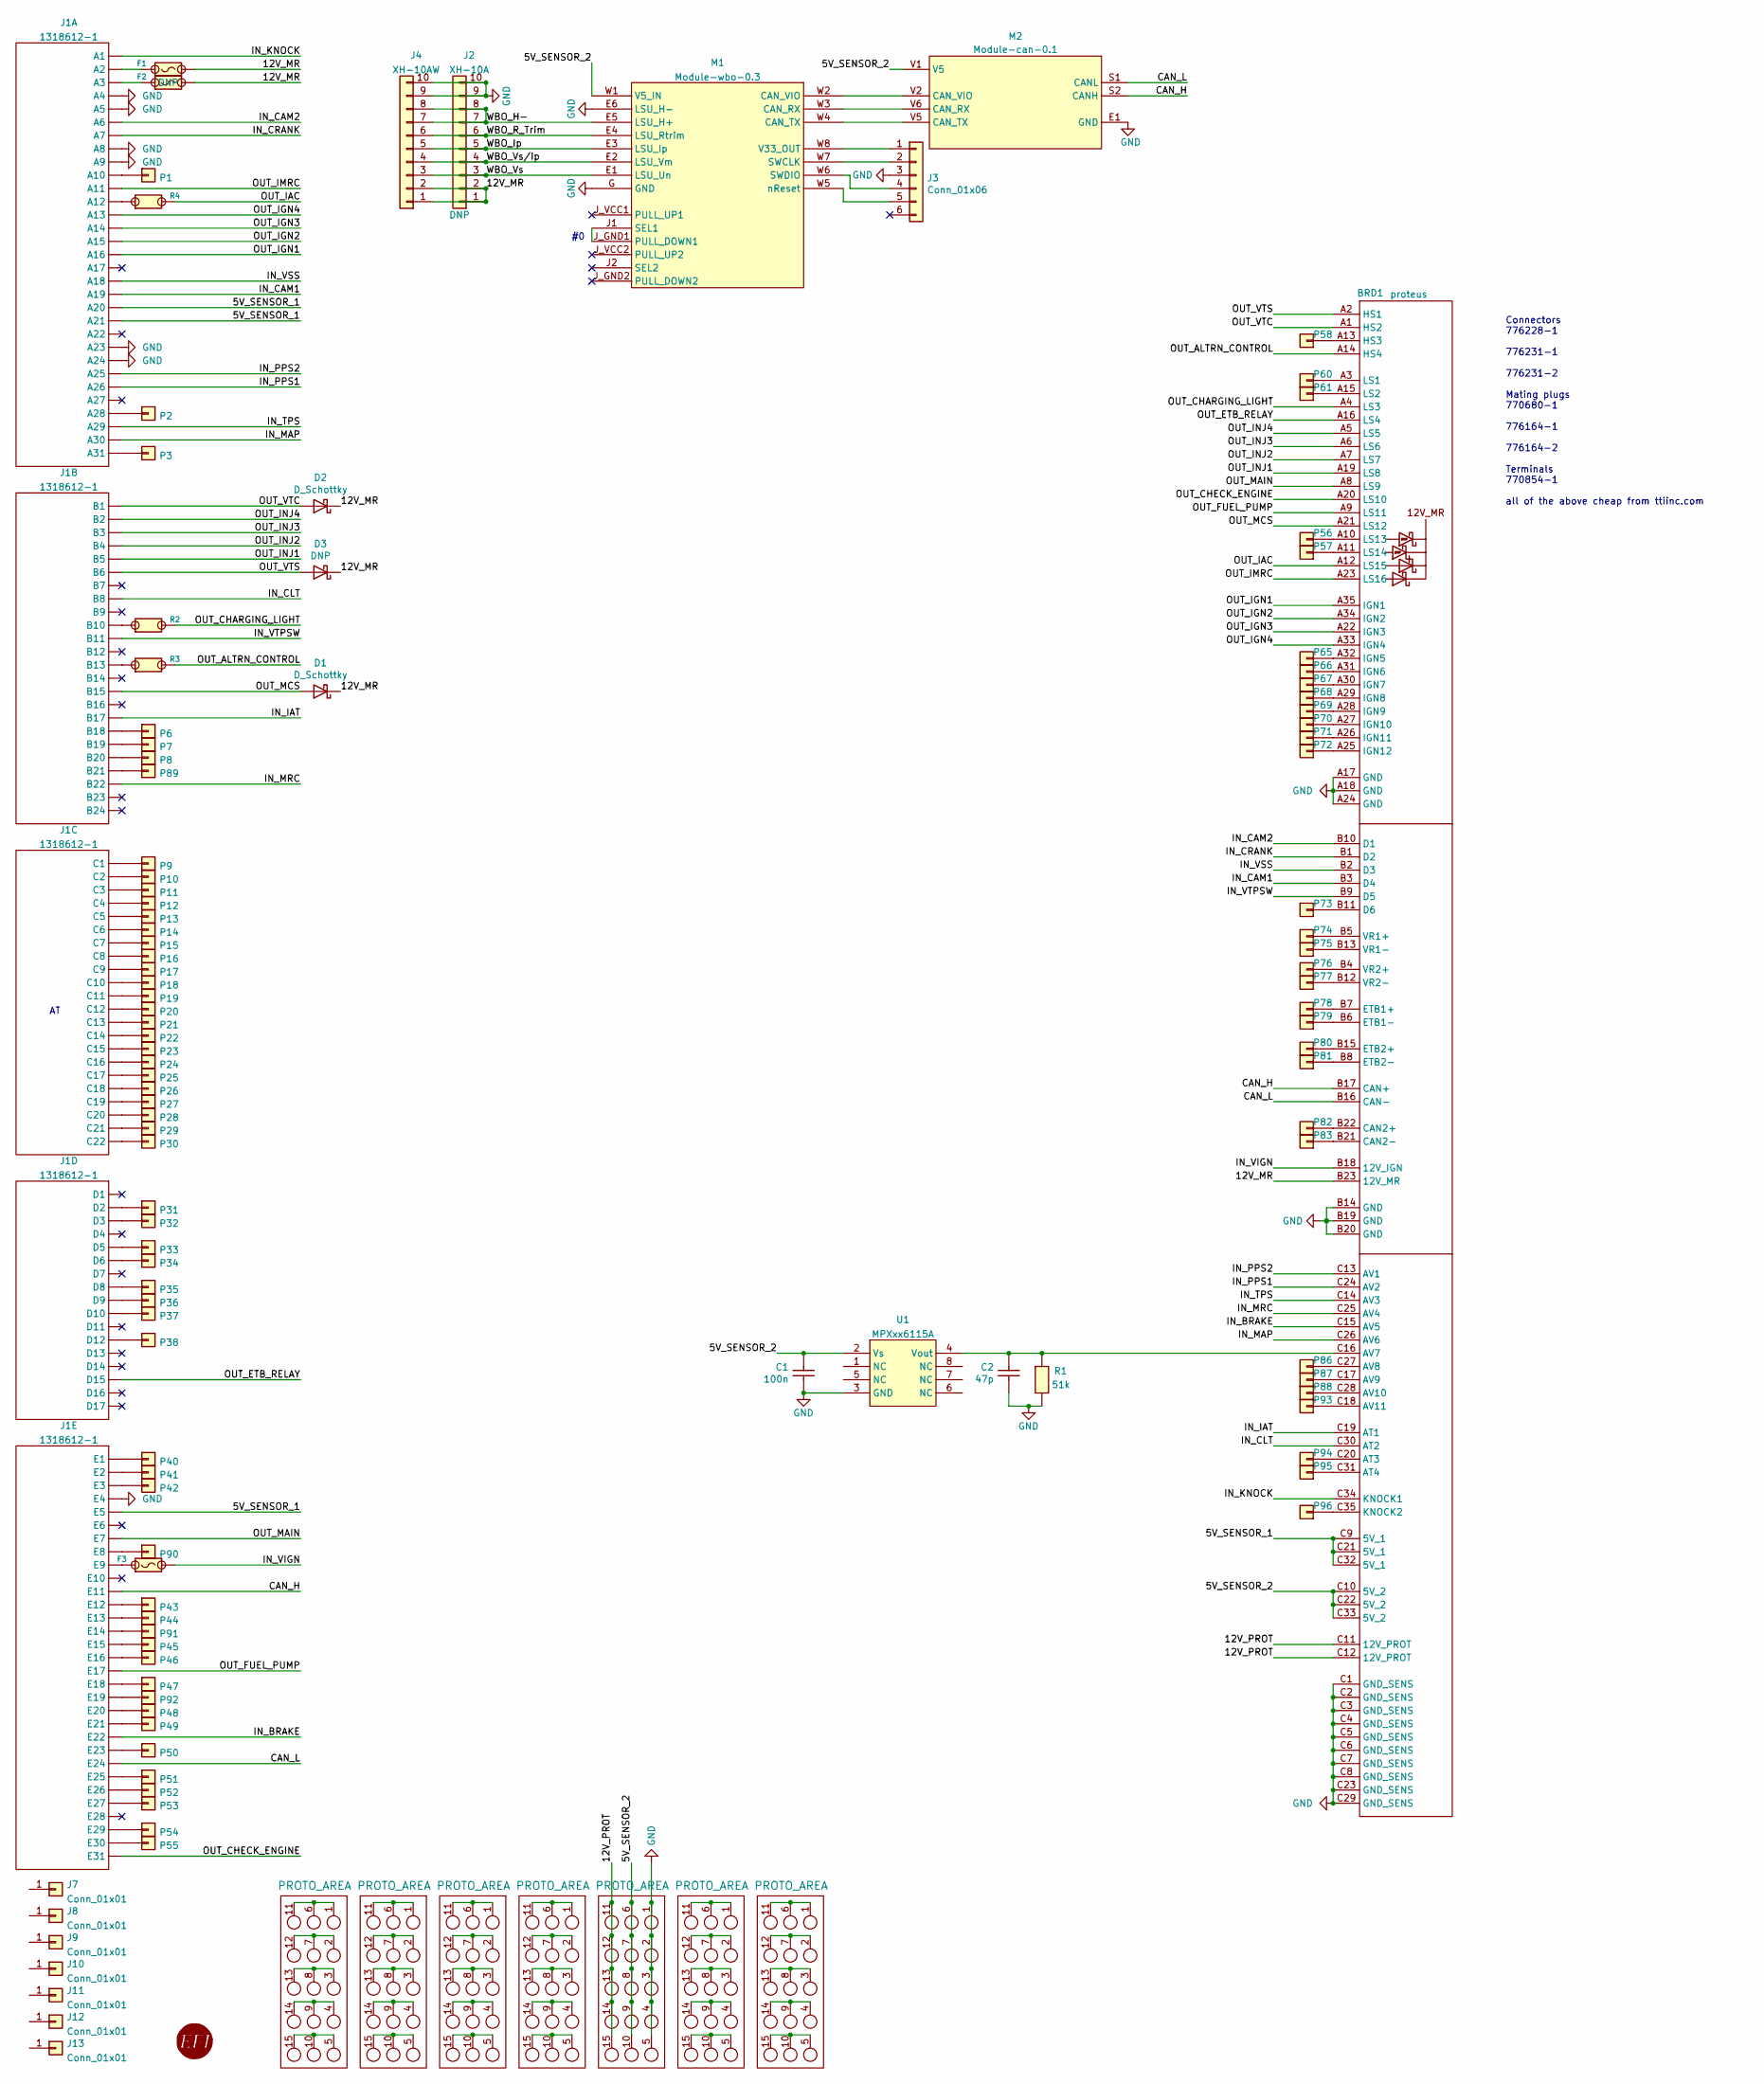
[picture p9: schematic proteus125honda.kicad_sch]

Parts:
BRD1: proteus
C1: 100n; C0603; LCSC C14663
C2: 47p; C0603; LCSC C1671
D1, D2: D_Schottky; D_SMA; LCSC C8678
D3: DNP; D_SMA
F1, F3: Fuse-Pad-Pad; PAD-1206-PAD; LCSC C182446
F2: Fuse-Pad-Pad; PAD-1206-PAD
G1, G2, G3, G4, G5, G7, G8: PROTO_AREA
G6: RUSEFI_LOGO; rusefi_logo
J1: 1318612-1; TE_1318612-1
J2: XH-10A; JST_XH_B10B-XH-A_1x10_P2.50mm_Vertical; LCSC C8885
J3: Conn_01x06; PinHeader_1x06_P2.54mm_Vertical
J4: XH-10AW; JST_XH_S10B-XH-A_1x10_P2.50mm_Horizontal; LCSC C14652
J7, J8, J9, J10, J11, J12, J13: Conn_01x01; MountingHole_4.5mm
M1: Module-wbo-0.3; wbo
M2: Module-can-0.1; can
P1, P2, P3, P6, P7, P8, P9, P10, P11, P12, P13, P14, P15, P16, P17, P18, P19, P20, P21, P22, P23, P24, P25, P26, P27, P28, P29, P30, P31, P32, P33, P34, P35, P36, P37, P38, P40, P41, P42, P43, P44, P45, P46, P47, P48, P49, P50, P51, P52, P53, P54, P55, P56, P57, P58, P60, P61, P65, P66, P67, P68, P69, P70, P71, P72, P73, P74, P75, P76, P77, P78, P79, P80, P81, P82, P83, P86, P87, P88, P89, P90, P91, P92, P93, P94, P95, P96: Pad; PAD-TH
R1: 51k; R0603; LCSC C23196
R2, R3, R4: Jumper-Pad-Pad; PAD-0805-PAD; LCSC C17477
U1: MPXxx6115A; MPX_SOP_SSOP

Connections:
/5V_SENSOR_1: BRD1.C9 (5V_1), BRD1.C21 (5V_1), BRD1.C32 (5V_1), J1.A20, J1.A21, J1.E5
/5V_SENSOR_2: BRD1.C10 (5V_2), BRD1.C22 (5V_2), BRD1.C33 (5V_2), C1.2, G5.6, G5.7, G5.8, G5.9, G5.10, M1.W1 (V5_IN), M2.V1 (V5), U1.2 (Vs)
/12V_MR: BRD1.B23 (12V_MR), D1.1 (K), D2.1 (K), D3.1 (K), F1.2, F2.2, J2.1, J2.2, J4.1, J4.2
/12V_PROT: BRD1.C11 (12V_PROT), BRD1.C12 (12V_PROT), G5.11, G5.12, G5.13, G5.14, G5.15
/CAN_H: BRD1.B17 (CAN+), J1.E11, M2.S2 (CANH)
/CAN_L: BRD1.B16 (CAN-), J1.E24, M2.S1 (CANL)
/IN_BRAKE: BRD1.C15 (AV5), J1.E22
/IN_CAM1: BRD1.B3 (D4), J1.A19
/IN_CAM2: BRD1.B10 (D1), J1.A6
/IN_CLT: BRD1.C30 (AT2), J1.B8
/IN_CRANK: BRD1.B1 (D2), J1.A7
/IN_IAT: BRD1.C19 (AT1), J1.B17
/IN_KNOCK: BRD1.C34 (KNOCK1), J1.A1
/IN_MAP: BRD1.C26 (AV6), J1.A30
/IN_MRC: BRD1.C25 (AV4), J1.B22
/IN_PPS1: BRD1.C24 (AV2), J1.A26
/IN_PPS2: BRD1.C13 (AV1), J1.A25
/IN_TPS: BRD1.C14 (AV3), J1.A29
/IN_VIGN: BRD1.B18 (12V_IGN), F3.2
/IN_VSS: BRD1.B2 (D3), J1.A18
/IN_VTPSW: BRD1.B9 (D5), J1.B11
/OUT_ALTRN_CONTROL: BRD1.A14 (HS4), R3.2
/OUT_CHARGING_LIGHT: BRD1.A4 (LS3), R2.2
/OUT_CHECK_ENGINE: BRD1.A20 (LS10), J1.E31
/OUT_ETB_RELAY: BRD1.A16 (LS4), J1.D15
/OUT_FUEL_PUMP: BRD1.A9 (LS11), J1.E17
/OUT_IAC: BRD1.A12 (LS15), R4.2
/OUT_IGN1: BRD1.A35 (IGN1), J1.A16
/OUT_IGN2: BRD1.A34 (IGN2), J1.A15
/OUT_IGN3: BRD1.A22 (IGN3), J1.A14
/OUT_IGN4: BRD1.A33 (IGN4), J1.A13
/OUT_IMRC: BRD1.A23 (LS16), J1.A11
/OUT_INJ1: BRD1.A19 (LS8), J1.B5
/OUT_INJ2: BRD1.A7 (LS7), J1.B4
/OUT_INJ3: BRD1.A6 (LS6), J1.B3
/OUT_INJ4: BRD1.A5 (LS5), J1.B2
/OUT_MAIN: BRD1.A8 (LS9), J1.E7
/OUT_MCS: BRD1.A21 (LS12), D1.2 (A), J1.B15
/OUT_VTC: BRD1.A1 (HS2), D2.2 (A), J1.B1
/OUT_VTS: BRD1.A2 (HS1), D3.2 (A), J1.B6
/WBO_H-: J2.7, J2.8, J4.7, J4.8, M1.E5 (LSU_H+)
/WBO_Ip: J2.5, J4.5, M1.E3 (LSU_Ip)
/WBO_R_Trim: J2.6, J4.6, M1.E4 (LSU_Rtrim)
/WBO_Vs: J2.3, J4.3, M1.E1 (LSU_Un)
/WBO_Vs/Ip: J2.4, J4.4, M1.E2 (LSU_Vm)
GND: BRD1.A17 (GND), BRD1.A18 (GND), BRD1.A24 (GND), BRD1.B14 (GND), BRD1.B19 (GND), BRD1.B20 (GND), BRD1.C1 (GND_SENS), BRD1.C2 (GND_SENS), BRD1.C3 (GND_SENS), BRD1.C4 (GND_SENS), BRD1.C5 (GND_SENS), BRD1.C6 (GND_SENS), BRD1.C7 (GND_SENS), BRD1.C8 (GND_SENS), BRD1.C23 (GND_SENS), BRD1.C29 (GND_SENS), C1.1, C2.1, G5.1, G5.2, G5.3, G5.4, G5.5, J1.A4, J1.A5, J1.A8, J1.A9, J1.A23, J1.A24, J1.E4, J2.9, J2.10, J3.3, J4.9, J4.10, M1.E6 (LSU_H-), M1.G (GND), M2.E1 (GND), R1.2, U1.3 (GND)
unnamed: BRD1.A3 (LS1), P60.1
unnamed: BRD1.A10 (LS13), P56.1
unnamed: BRD1.A11 (LS14), P57.1
unnamed: BRD1.A13 (HS3), P58.1
unnamed: BRD1.A15 (LS2), P61.1
unnamed: BRD1.A25 (IGN12), P72.1
unnamed: BRD1.A26 (IGN11), P71.1
unnamed: BRD1.A27 (IGN10), P70.1
unnamed: BRD1.A28 (IGN9), P69.1
unnamed: BRD1.A29 (IGN8), P68.1
unnamed: BRD1.A30 (IGN7), P67.1
unnamed: BRD1.A31 (IGN6), P66.1
unnamed: BRD1.A32 (IGN5), P65.1
unnamed: BRD1.B4 (VR2+), P76.1
unnamed: BRD1.B5 (VR1+), P74.1
unnamed: BRD1.B6 (ETB1-), P79.1
unnamed: BRD1.B7 (ETB1+), P78.1
unnamed: BRD1.B8 (ETB2-), P81.1
unnamed: BRD1.B11 (D6), P73.1
unnamed: BRD1.B12 (VR2-), P77.1
unnamed: BRD1.B13 (VR1-), P75.1
unnamed: BRD1.B15 (ETB2+), P80.1
unnamed: BRD1.B21 (CAN2-), P83.1
unnamed: BRD1.B22 (CAN2+), P82.1
unnamed: BRD1.C16 (AV7), C2.2, R1.1, U1.4 (Vout)
unnamed: BRD1.C17 (AV9), P87.1
unnamed: BRD1.C18 (AV11), P93.1
unnamed: BRD1.C20 (AT3), P94.1
unnamed: BRD1.C27 (AV8), P86.1
unnamed: BRD1.C28 (AV10), P88.1
unnamed: BRD1.C31 (AT4), P95.1
unnamed: BRD1.C35 (KNOCK2), P96.1
unnamed: F1.1, J1.A2
unnamed: F2.1, J1.A3
unnamed: F3.1, J1.E9
unnamed: G1.1, G1.6, G1.11
unnamed: G1.5, G1.10, G1.15
unnamed: G1.2, G1.7, G1.12
unnamed: G1.3, G1.8, G1.13
unnamed: G1.4, G1.9, G1.14
unnamed: G2.1, G2.6, G2.11
unnamed: G2.5, G2.10, G2.15
unnamed: G2.2, G2.7, G2.12
unnamed: G2.3, G2.8, G2.13
unnamed: G2.4, G2.9, G2.14
unnamed: G3.1, G3.6, G3.11
unnamed: G3.5, G3.10, G3.15
unnamed: G3.2, G3.7, G3.12
unnamed: G3.3, G3.8, G3.13
unnamed: G3.4, G3.9, G3.14
unnamed: G4.1, G4.6, G4.11
unnamed: G4.5, G4.10, G4.15
unnamed: G4.2, G4.7, G4.12
unnamed: G4.3, G4.8, G4.13
unnamed: G4.4, G4.9, G4.14
unnamed: G7.1, G7.6, G7.11
unnamed: G7.5, G7.10, G7.15
unnamed: G7.2, G7.7, G7.12
unnamed: G7.3, G7.8, G7.13
unnamed: G7.4, G7.9, G7.14
unnamed: G8.1, G8.6, G8.11
unnamed: G8.5, G8.10, G8.15
unnamed: G8.2, G8.7, G8.12
unnamed: G8.3, G8.8, G8.13
unnamed: G8.4, G8.9, G8.14
unnamed: J1.A10, P1.1
unnamed: J1.A12, R4.1
unnamed: J1.A28, P2.1
unnamed: J1.A31, P3.1
unnamed: J1.B10, R2.1
unnamed: J1.B13, R3.1
unnamed: J1.B18, P6.1
unnamed: J1.B19, P7.1
unnamed: J1.B20, P8.1
unnamed: J1.B21, P89.1
unnamed: J1.C1, P9.1
unnamed: J1.C2, P10.1
unnamed: J1.C3, P11.1
unnamed: J1.C4, P12.1
unnamed: J1.C5, P13.1
unnamed: J1.C6, P14.1
unnamed: J1.C7, P15.1
unnamed: J1.C8, P16.1
unnamed: J1.C9, P17.1
unnamed: J1.C10, P18.1
unnamed: J1.C11, P19.1
unnamed: J1.C12, P20.1
unnamed: J1.C13, P21.1
unnamed: J1.C14, P22.1
unnamed: J1.C15, P23.1
unnamed: J1.C16, P24.1
unnamed: J1.C17, P25.1
unnamed: J1.C18, P26.1
unnamed: J1.C19, P27.1
unnamed: J1.C20, P28.1
unnamed: J1.C21, P29.1
unnamed: J1.C22, P30.1
unnamed: J1.D2, P31.1
unnamed: J1.D3, P32.1
unnamed: J1.D5, P33.1
unnamed: J1.D6, P34.1
unnamed: J1.D8, P35.1
unnamed: J1.D9, P36.1
unnamed: J1.D10, P37.1
unnamed: J1.D12, P38.1
unnamed: J1.E1, P40.1
unnamed: J1.E2, P41.1
unnamed: J1.E3, P42.1
unnamed: J1.E8, P90.1
unnamed: J1.E12, P43.1
unnamed: J1.E13, P44.1
unnamed: J1.E14, P91.1
unnamed: J1.E15, P45.1
unnamed: J1.E16, P46.1
unnamed: J1.E18, P47.1
unnamed: J1.E19, P92.1
unnamed: J1.E20, P48.1
unnamed: J1.E21, P49.1
unnamed: J1.E23, P50.1
unnamed: J1.E25, P51.1
unnamed: J1.E26, P52.1
unnamed: J1.E27, P53.1
unnamed: J1.E29, P54.1
unnamed: J1.E30, P55.1
unnamed: J3.1, M1.W8 (V33_OUT)
unnamed: J3.2, M1.W7 (SWCLK)
unnamed: J3.4, M1.W6 (SWDIO)
unnamed: J3.5, M1.W5 (nReset)
unnamed: M1.J1 (SEL1), M1.J_GND1 (PULL_DOWN1)
unnamed: M1.W2 (CAN_VIO), M2.V2 (CAN_VIO)
unnamed: M1.W3 (CAN_RX), M2.V6 (CAN_RX)
unnamed: M1.W4 (CAN_TX), M2.V5 (CAN_TX)

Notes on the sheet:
Connectors 776228-1 776231-1 776231-2 Mating plugs 770680-1 776164-1 776164-2 Terminals 770854-1 all of the above cheap from ttiinc.com

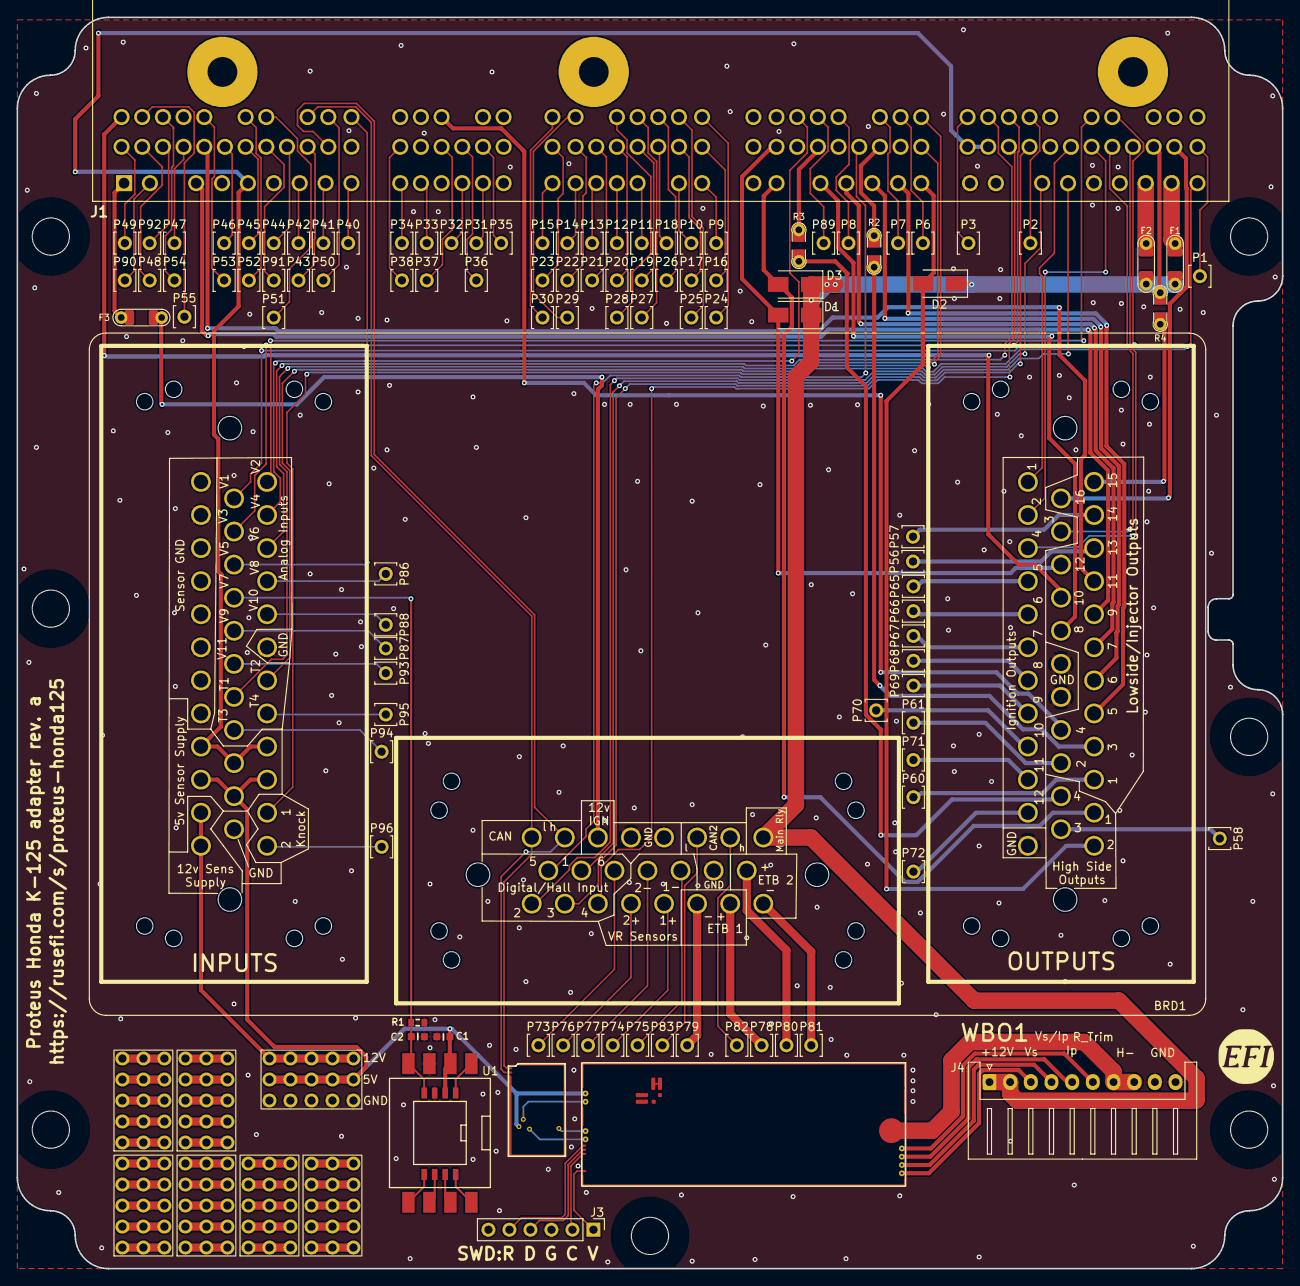
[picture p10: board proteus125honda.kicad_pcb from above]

Board: 2 copper layers, 153.0 x 151.3 mm, 121 parts (0 on the bottom side), 178 nets.

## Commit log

2021-09-24 Upd pinout
    [proteus125honda.kicad_sch]
2021-09-28 Upd pcb
    [proteus125honda.kicad_pcb, proteus125honda.kicad_sch]
2021-09-30 Proteus-compatible component
    [proteus125honda.kicad_pcb, proteus125honda.kicad_sch]
2021-09-30 Proteus-compatible board preview
    [proteus125honda.kicad_pcb, proteus125honda.kicad_sch]
2021-10-01 Fix proteus
    [proteus125honda.kicad_pcb, proteus125honda.kicad_sch]
2021-10-03 #17, #18, #14, #13
    [proteus125honda.kicad_pcb, proteus125honda.kicad_sch]
2021-10-09 update hellen-one and rename/move some files
    [bom_replace_125honda-a.csv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]
2021-10-09 update gerber path in kicad files
    [proteus125honda.kicad_pcb]
2021-10-11 Fresh outputs
    [125honda-BOM.csv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]
2021-10-11 Fab time?
    [125honda.DRL, 125honda.GBL, 125honda.GBO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]
